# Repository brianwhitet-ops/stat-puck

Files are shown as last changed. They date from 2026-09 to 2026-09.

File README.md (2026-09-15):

# Stat Puck

Magnetic golf-cart score puck — e-ink + 5 buttons, offline on-course, BLE sync after the round.

## Repo

**https://github.com/brianwhitet-ops/stat-puck**

Full design pack zip: [v0.1.0 release](https://github.com/brianwhitet-ops/stat-puck/releases/tag/v0.1.0) (`stat-puck-full.zip`)

## Concepts

| On cart | In hand | Exploded | Mount |
| --- | --- | --- | --- |
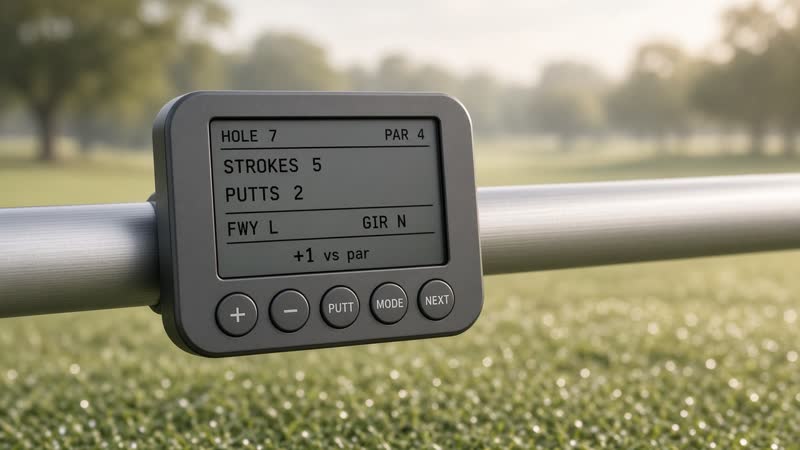
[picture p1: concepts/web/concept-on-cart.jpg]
on cart
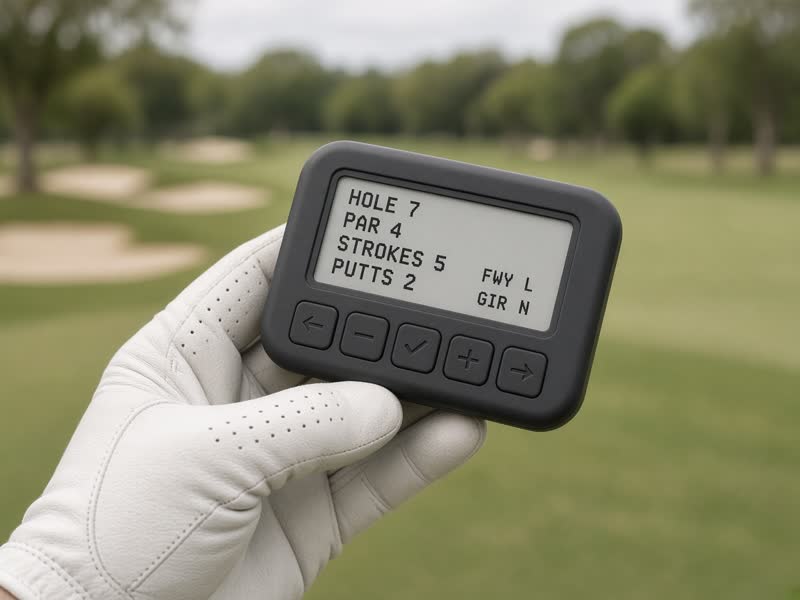
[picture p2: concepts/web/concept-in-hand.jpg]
in hand
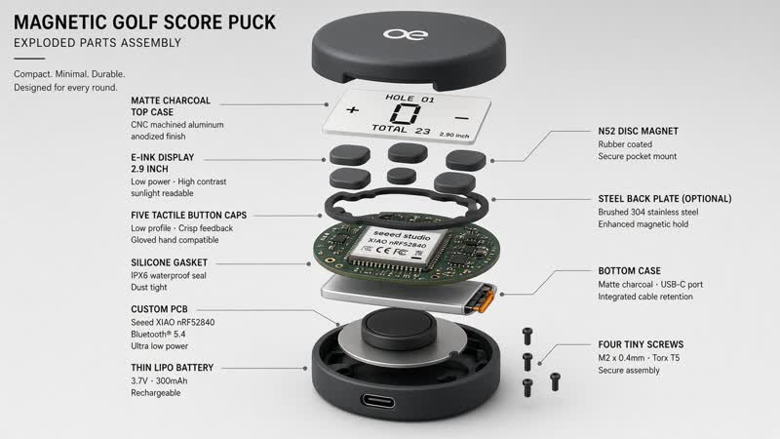
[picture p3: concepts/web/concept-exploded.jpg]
exploded
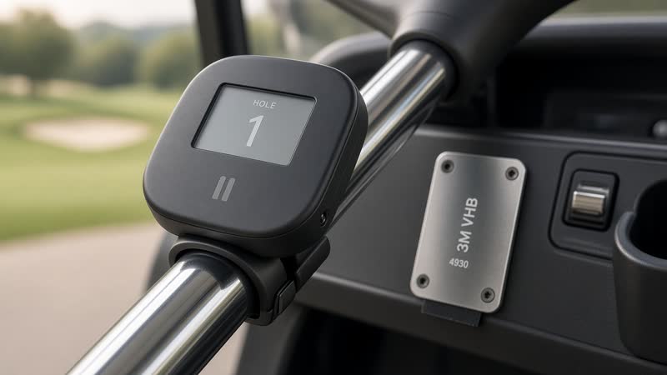
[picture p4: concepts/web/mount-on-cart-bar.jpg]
mount
|  |  |  |  |

## Assembly animation

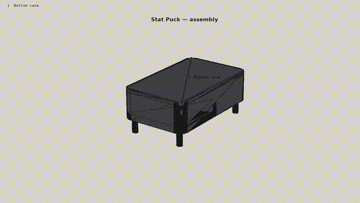
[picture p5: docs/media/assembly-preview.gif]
Assembly


Full MP4 is in the [v0.1.0 release zip](https://github.com/brianwhitet-ops/stat-puck/releases/download/v0.1.0/stat-puck-full.zip).

## Deliverables

| Path | What |
| --- | --- |
| `concepts/web/` | On-cart, in-hand, exploded, mount-on-bar concept images |
| `docs/SPEC.md` | One-page mechanical / electrical / firmware / cost spec |
| `docs/FIRMWARE_PLAN.md` | MVP tasks + 7-day bench plan |
| `docs/ORDER_MEMO.md` | What to order and why |
| `docs/RISKS.md` | Rental plastic, e-ink lag, bounce, NEXT, double-post, GHIN gate |
| `docs/SYNC_PAYLOAD.md` | Phone export schema (no invented GHIN API) |
| `bom/BOM.md` | Annotated BOM with vendor links + first-prototype cart |
| `cad/` | STEP + STL: enclosure, internals, steel plate, clamp |
| `docs/media/assembly-preview.gif` | Labeled assembly preview |
| `datasheets/` | Notes + linked vendor PDFs |
| `firmware/PINMAP.md` | Week-1 bring-up pin map |
| `firmware/` | Slab UI/state + host visual tests (`firmware/README.md`) |
| `design/instinct-firmware-goldens-pr1/` | Instinct-locked 296×128 goldens + SHA256SUMS |

## Device (P1)

- **MCU:** Seeed XIAO nRF52840 (USB-C, BLE) → production Raytac MDBT50Q-1MV2
- **Display:** Waveshare 2.9" e-Paper 296×128 (SPI)
- **Buttons:** 5× Omron B3W-1000 (IP67) — `+` `−` `PUTT` `MODE` `NEXT`
- **Magnet:** K&J DC6TP-N52 rubber-coated N52, **13.12 lb** Case-1 pull
- **Battery:** 500 mAh protected LiPo
- **Mount:** magnet pocket + steel plate/VHB for plastic carts + optional bar clamp

## UX (in-round)

```
HOLE 7  PAR 4
STROKES  5
PUTTS    2
FWY  L   GIR  N
+1
```

Defaults: strokes = par, putts = 2, GIR auto-suggest, FWY N/A on par 3. No rangefinder, no live GHIN, no on-device handicap.

## Regenerate CAD / animation

```bash
python3 cad/generate_enclosure.py
python3 animation/make_animation.py
```

## License

Prototype design files: MIT for CAD/firmware sketches. Vendor datasheets remain their respective copyrights.

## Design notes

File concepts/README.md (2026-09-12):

# Concepts

Web-optimized concept renders live in `web/`.

- On cart
- In hand
- Exploded
- Mount on cart bar

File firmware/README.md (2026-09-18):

# Slab firmware workstream

This branch builds on firmware PR #1. The companion app change builds on PR #3. Neither existing branch needs to be merged to review these changes, and no main branch merge or public website deployment is part of this work.

Read `../protocol/README.md` for the v2 contract and integration boundary. Read `../docs/SOFTWARE-HANDOFF-2026-09-18.md` for remaining vendor work.

## Implemented here

- Explicit zero-start capture flags; no par/two-putt/fairway prefills.
- Missing data stays null on the wire and stays out of statistics.
- Explicit 9/18 Quick Start and end-as-nine at the turn.
- Unique round ids from the XIAO silicon identity and a persisted sequence; golden fixtures are explicitly bench-only.
- Ten-round FIFO, queue-full backpressure, non-destructive chunk reads, identity/checksum-bound ACK retirement.
- Versioned two-slot save journal for active and completed rounds. UI/save failures stop progress instead of showing a false success.
- Protocol v2 C encoder with bounded output and a matching TypeScript implementation.

## Verification

```sh
make -C firmware/host test
make -C firmware/host visual
make -C firmware/host fixtures
python -m platformio run -e xiaoble -d firmware
```

Host tests run state, packed-device framebuffer, protocol/queue and byte-by-byte interrupted-write checks. `visual` compares six original fixtures without overwriting their goldens. Additional renders show zero-start and unentered-putt behavior. Tests are software evidence only.

## Still unimplemented or unverified

Real GATT advertising/transfer and ACK callbacks; phone/native BLE bridge; course-card download; signed DFU/rollback/provisioning; production board support; measured current and sleep optimization; real-panel refresh, button timing, RF range, environmental tests and physical power-cut testing. The existing blocking display driver pauses button polling during refresh and requires hardware timing work. No production battery-life claim is made.

Provision the filesystem separately on fresh boards. Normal startup only mounts it; it never invokes the SDK auto-format path. A mount failure shows a storage error and preserves the medium for service.

The selected development platform is the existing XIAO Adafruit/Arduino bench framework. This work does not select the production MCU, radio stack or bootloader. Large frame/store/journal workspaces are static to avoid overflowing the small Arduino loop-task stack. Integrators must serialize access and measure stack high-water and flash wear on hardware.

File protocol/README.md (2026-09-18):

# Slab round protocol v2

Implementation proposal for review, 2026-09-18. This supersedes the two incompatible round payload scaffolds in firmware PR #1 and app PR #3 on these new branches. It does not freeze production hardware or authorize changing the owner-approved battery, ingress, drop, mount or firmware-update requirements.

## Implementation boundary

The C encoder, queue/chunk reader, TypeScript decoder, receiver and durable import coordinator are implemented and software-tested. The XIAO radio remains a stub. There is no working GATT service, native iOS/Android BLE bridge, course-card receiver or DFU implementation in this change. Do not demonstrate an app simulation as a working wireless device.

The app and firmware PRs both carry the same `protocol/` directory. Before combining them, verify those files are identical. The app re-exports the shared TypeScript types; it does not maintain a third schema.

## Round payload

`schema_version` is now **2** because nullable capture fields, sequence and checksum semantics differ from both v1 scaffolds. Unsupported schemas and extra fields are preserved and rejected without ACK. No automatic v1 conversion is attempted: the old firmware cannot distinguish real input from its prefilled scores.

| Field | Rule |
| --- | --- |
| `schema_version` | Integer 2 |
| `round_id` | Opaque ASCII identifier, 1 to 64 characters from A-Z, a-z, 0-9, colon, underscore, hyphen |
| `device_id` | Same character set, 1 to 48 characters |
| `round_sequence` | Integer 1 through 4294967295, monotonically allocated and committed before play |
| `holes_played` | Numeric 9 or 18, explicitly chosen |
| `holes` | Exactly 9 or 18 entries in ascending contiguous order, including entries with unknown values |
| `hole` | Integer index 1 through `holes_played` |
| `par` | 3, 4, 5, or null when course metadata is unavailable |
| `strokes` | Entered integer 1 through 15, or null if unentered |
| `putts` | Entered integer 0 through 10, or null if unentered; entered putts require entered strokes and cannot exceed them |
| `drive_result` | `left`, `fairway`, `right`, or null; always null on par 3 |
| `totals.strokes`, `totals.putts` | Sum only when every hole has that field entered; otherwise null, never a misleading partial total |
| `checksum` | Lowercase `crc32:xxxxxxxx`, CRC-32/ISO-HDLC over the canonical UTF-8 body excluding this field |

GIR is derived only when par, strokes and putts are known. Unknown GIR is null, not false. Fairway percentages exclude unknown drive results and unknown course pars. The approved GIR approximation is retained; no extra shot-tracking facts are invented.

Canonical property order is defined by `canonicalBody()` and the C encoder. Hole properties are ordered `hole, par, strokes, putts, drive_result`. No whitespace is emitted. Unknown timestamps and course names are not fabricated; the app can attach course metadata and its own import timestamp outside the captured payload. CRC detects corruption; it is not authentication or a firmware signature.

`fixtures/` contains actual C output for untouched holes, a nine-hole round with explicitly entered zero putts, and a completed eighteen-hole fixture. App tests check those bytes against the TypeScript canonicalizer and checksum.

## Transfer and acknowledgment

1. Transfer is allowed only after round completion, in the sync screen. All accepted score changes and completed rounds must be persisted before a saved message or radio transfer is enabled.
2. Select the oldest queued round by device sequence, not a phone clock or similarity of course/date. One round transfers at a time.
3. The transport begins a transfer with the five `RoundAck` fields below plus `byte_length` (1 to 4096). It must bind the transfer to that exact immutable round.
4. Transfer chunks carry an explicit byte offset. Chunk size follows the negotiated transport capacity. The reference receiver accepts contiguous chunks and identical overlapping retransmissions. Gaps, changed replay bytes, overflow and incomplete payloads do not produce an ACK. Reconnect may safely restart at offset zero.
5. Parse, validate, checksum and compare transfer identity. Preserve unsupported raw payloads; keep the device copy. Never partially create a round.
6. Commit the validated round in a durable atomic app transaction. `round_id` is the idempotency key. An identical duplicate updates sync metadata only; it never replaces captured data, edits, provenance or the original import time. A different payload using the same id is a conflict and gets no ACK.
7. Only after that transaction completes may the app send ACK with `schema_version, round_id, device_id, round_sequence, checksum`.
8. The device checks all ACK fields against the oldest round in the session. Copy the store, apply `slab_store_ack`, persist the copy, then publish it and send a success result. If any step fails, retain the old store and report failure. A repeated ACK for an already removed round must not remove the next round. The low-level reference returns NOT_FOUND/CONFLICT in that case; the bridge should re-enumerate the queue.
9. `sendAck()` in the app must resolve on that persisted device result. An ATT write response alone is not proof the device committed retirement. If the result is lost, reconnect and re-enumerate; any retransmitted round is an idempotent duplicate.

The production BLE adapter must implement discovery/pairing, GATT UUIDs/characteristics, fragmentation of control messages, authorization of destructive ACKs, connection/session cleanup, retry timeouts and phone permission handling. Those transport decisions remain integration work; this document does not pretend to have selected or tested them. No firmware image bytes belong in this round service.

The app's IndexedDB adapter requires a transaction that reports `strict` durability and waits for its completion event. Engines that ignore the durability option receive no ACK. This follows the [IndexedDB durability contract](https://w3c.github.io/IndexedDB/#dom-idbtransaction-durability); software tests use an in-memory IndexedDB model and cannot prove phone disk behavior. Production integration still needs device testing, storage-retention policy and backup/recovery decisions.

## Device storage

The reference store supports one active round plus ten completed rounds, with backpressure before another round starts when the queue is full. Storage is a two-slot journal with version, size, sequence and CRC checks, flushed writes and readback. An interrupted inactive-slot write preserves the previous committed snapshot. Both slots corrupt or an old unsupported `/slab_round.bin` stops normal operation for service; it never silently resets the device.

The XIAO startup calls the base mount-only filesystem operation. Its usual `InternalFS.begin()` would auto-format on mount failure and is deliberately not used. A fresh unformatted device requires an explicit factory/service format; the application will not format it automatically.

Snapshots currently persist the versioned C structure layout. They are not a cross-compiler or future-firmware storage ABI. A production port must define and test migrations before changing layouts. A factory reset must preserve identity/sequence or provision a new identity namespace so old round ids cannot be reused.

These APIs use fixed workspaces and are serialized main-task APIs, not reentrant or ISR-safe. The device bridge must synchronize reads, saves, completion and ACK processing. The host file adapter is test infrastructure, not a certified database. A/B files share the underlying LittleFS medium; software fault tests do not establish real flash/brownout robustness, endurance, or the 30-day retention target.

## User interactions introduced for review

- Quick Start selects 9 or 18 holes with +/- and starts with NEXT. Unknown par/yardage remains unknown.
- Strokes begin at zero and require +/- entry. NEXT cannot promote an untouched zero into a score.
- Putts require explicit entry too. Minus at zero deliberately records a zero-putt hole; NEXT alone does not.
- Drive is initially unset. First + selects left; first - selects right; later inputs cycle L/fairway/R. Leaving it unset records null.
- At the turn, hold NEXT on untouched hole 10 to finish as nine. Holding NEXT after completion opens Quick Start for another round.
- NEXT is emitted on short release or once at the long-press threshold, never both. PUTT remains physically unchanged and ignored as in the approved sequential flow.

The original six visual fixture goldens remain unchanged. The new Quick Start, unentered fields and device storage-error screens need owner usability review and real-panel testing.

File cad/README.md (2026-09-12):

# CAD

Generate with `python3 cad/generate_enclosure.py` (build123d).

Exports: `device_assembly.step/.stl`, enclosure top/bottom, optional clamp, steel plate, cart mount demo.

Envelope 110×58×15.5 mm; magnet pocket Ø19.2×9.6; 5 buttons pitch 16 mm; USB-C on short edge.

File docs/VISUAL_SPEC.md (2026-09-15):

# Visual spec — Instinct REDO (296×128)

**Source of truth:** `design/instinct-firmware-goldens-pr1/`  
Hashes: `design/instinct-firmware-goldens-pr1/SHA256SUMS.txt`  
Note: `design/instinct-firmware-goldens-pr1/REDO-NOTE.md`

These native 296×128 RGBA frames replace the prior host 1-bit scorecard. No layout reinterpretation.

| File | State | Locked copy |
| --- | --- | --- |
| `01-default-hole.png` | `DEFAULT_HOLE` | Big score (par). `HOLE 07` · `PAR 4 · 412 YD`. `E · THROUGH 6`. No FWY/GIR. |
| `02-stroke-edit.png` | `STROKE_EDIT` | `STROKES` · − 4 + · `PRESS DIAL TO KEEP` |
| `03-putts-input.png` | `PUTTS_INPUT` | `PUTTS` · − 2 + · `PRESS DIAL TO KEEP` |
| `04-end-hole-confirm.png` | `END_HOLE_CONFIRM` | `DONE` · strokes/putts · drive LEFT / **FAIRWAY** / RIGHT · `PRESS DIAL` |
| `05-round-complete-sync.png` | `ROUND_COMPLETE_SYNC` | `ROUND COMPLETE` · 74 · +2 · `READY TO SYNC` · `OPEN SLAB ON PHONE` |
| `06-derived-stats.png` | `DERIVED_STATS` | `ROUND STATS` · GIR 11/18 61% · putting 31 / 1.72 per hole · `COMPUTED FROM SCORE+PUTTS` |
| `slab-screen-states-contact-sheet.png` | (sheet) | Instinct 2×3 |

Host `slab_ui_render` starts from the locked frame (zlib-baked in `firmware/src/slab_frames.c`) and composes live fields from `slab_round_t`. With the fixture/demo values these goldens encode, pixel-diff must be zero vs these PNGs. Other live values change those field pixels.

Behavior (unchanged): strokes → putts → done; no GIR prompt; drive L/fairway/R on par 4/5 only; BLE advertise only in `ROUND_COMPLETE_SYNC`.

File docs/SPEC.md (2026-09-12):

# Stat Puck — One-Page Spec

**Product:** Magnetic golf-cart score puck (Teenage Engineering–style slab)  
**Prototype codename:** `stat-puck`  
**Sync model:** Offline during round → BLE pull to phone after 18 (or 9) → phone posts later  

---

## Mechanical

| Item | Spec |
| --- | --- |
| Envelope | 110 × 58 × 15.5 mm, rounded slab, matte charcoal |
| Mass target | < 150 g (prototype estimate ~95–120 g) |
| Mount | N52 rubber-coated disc (K&J **DC6TP-N52**, Ø19.05 × 9.52 mm, **13.12 lb** Case-1 pull) in bottom pocket |
| Rental carts | Include 70 × 40 × 1.2 mm steel plate + 3M VHB tape (no ferrous metal on plastic bodies) |
| Optional | Secondary clamp for Ø22–28 mm Club Car / EZGO bar |
| Sealing | Silicone gasket in split line + IP67 Omron **B3W** switches; target **IP67-ish** (not lab-certified on rev A) |
| Aesthetic | Hidden M2 fasteners, no toy colors, no pelican ribs |

## Electrical

| Block | Choice | Notes from datasheets |
| --- | --- | --- |
| MCU + BLE | Seeed **XIAO nRF52840** (DigiKey 102010448) for P1; production → Raytac **MDBT50Q-1MV2** | USB-C, BLE 5.x, BQ25101 charger on XIAO; Raytac: 10.5×15.5×2.05 mm, VDD **1.7–5.5 V**, Nordic nRF52840 |
| Display | Waveshare **2.9" e-Paper** 296×128 | Panel outline **36.7×79.0×1.05 mm**; module **89.5×38 mm**; **4-wire SPI**; full refresh ~3 s, partial ~0.6 s; standby ≈0 |
| Buttons | 5× Omron **B3W-1000** | **IP67** (except terminals), bounce **≤5 ms**, OF **1.57 N** |
| Battery | Adafruit **1578** 3.7 V **500 mAh** LiPo w/ protection | 36×29×4.75 mm; charge via XIAO |
| Magnet | K&J **DC6TP-N52** | Rubber coat, water-resistant, non-scratch |

## Firmware states

```
BOOT → IDLE_PAIR → LOAD_CARD → IN_ROUND → TURN_SYNC? → END_ROUND_SYNC → SLEEP
```

Defaults: strokes=par, putts=2, GIR suggest `(strokes−putts)≤(par−2)`, FWY N/A on par 3. No on-device handicap. No live GHIN.

## Phone app (specify only)

Pick course + tees → push pars; pull card; one-screen edits; export payload; GHIN auth later (partner). Never invent a public GHIN API.

## BOM cost targets

| Qty | Target |
| --- | --- |
| 100 | **< $40** |
| 5 000 | **< $15** |

P1 shopping cart ~$70–90 (dev modules).

## Risks

Rental-cart plastic (need steel plate); e-ink lag (partial refresh); wet bounce (IP67+debounce); accidental NEXT (hold confirm); double-post (`round_id`); GHIN partner-gated.

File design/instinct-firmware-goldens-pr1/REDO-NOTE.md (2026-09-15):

# Instinct firmware visual REDO (2026-09-15 ~2:27pm ET)

Source: Instinct emails on lane.whitet@agentmail.to
- Main: Re: Brian connected us — Checkpoint verdict REDO visual layer
- Side: Slab firmware goldens 5-6 - use in PR #1

Order: Preserve behavior/state-machine; replace render layer. Check these native 296x128 PNGs into PR #1 as only visual source of truth; pixel-diff tests; no layout reinterpretation.

States:
1. 01-default-hole.png
2. 02-stroke-edit.png
3. 03-putts-input.png
4. 04-end-hole-confirm.png
5. 05-round-complete-sync.png
6. 06-derived-stats.png
+ slab-screen-states-contact-sheet.png

Next gate after emulator parity: on-device photos of all six under direct light + measured refresh.
States 5-6 UPDATED from Instinct goldens email (hashes differ from prior F-reference copies).

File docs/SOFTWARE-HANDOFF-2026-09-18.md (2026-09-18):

# Slab software handoff for scope review

Status: reviewable software implementation, not EVT validation. No communication has been sent to the manufacturer and no hardware has been purchased or ordered.

## Work supplied for review

| Area | Delivered | What the hardware partner retains |
| --- | --- | --- |
| Product behavior | Zero-start scoring, explicit capture, missing-data-aware statistics, 9/18 lifecycle, single-action NEXT handling | Real buttons, glove use, timing, display and usability integration |
| Round interface | One v2 schema, matching C/TypeScript encoders/validators and C-generated compatibility fixtures | BLE transport, pairing, GATT services, native phone integration and RF validation |
| Saved rounds | Ten-round queue, sequence identities, copy/commit ACK retirement and two-slot journal | Production NVM layout, migrations, flash wear, electrical power-loss tests and retention validation |
| App import | Bounded receiver, duplicate/conflict handling, IndexedDB transaction adapter and ACK-after-commit coordinator | Connecting these modules to the app UI/native BLE bridge and proving durability on representative phones |
| Verification | C state/protocol/fault tests, app transaction/compatibility tests and existing visual regression checks | End-to-end physical testing and defect correction |

The mobile app remains outside the manufacturer's quoted development scope. Its companion implementation supports integration and reduces overall project work; it does not by itself remove a line from their hardware fee.

## Scope that remains with the hardware partner

Production electrical architecture, component sourcing, schematic, PCB layout, antenna and magnet/cart interaction, charging and protection, production display selection, enclosure/clamp/seals, fabrication, assembly and integrated EVT validation. Signed BLE firmware update and recovery are still required and still unimplemented. No owner-approved battery, ingress, drop or RF target has been reduced.

There is no complete production CAD assembly, custom schematic or PCB supplied by this software change. Do not describe the original concept CAD as manufacturing-ready.

## Decisions made explicitly in this implementation

- Use schema v2 rather than relabeling incompatible v1 data.
- Represent unentered performance as null and use explicit capture flags on device.
- Require an explicit minus press to record zero putts. Untouched NEXT cannot fabricate a fact.
- Quick Start leaves par and yardage unknown until a course is supplied. No demo course is silently assigned.
- Use a ten-round capacity as the package's proposed implementation default, with no expiry or automatic eviction.
- Use mount-only startup rather than the SDK auto-format-on-failure routine. A fresh device requires factory/service filesystem provisioning.
- Preserve unsupported legacy files for service; no unsafe migration from prefilled scores.
- Keep the bench framework for now. Obtain vendor agreement before a production port or bootloader architecture is frozen.

## Acceptance before reducing outsourced scope

The partner should review the source, confirm which modules they will reuse, and price removed implementation separately from retained review, adaptation and integration. Source supplied is not automatically equivalent to supplier hours removed. Keep one named owner for integrated prototype behavior.

The statement of work should specify evidence for score capture, lossless queued sync, interrupted transfer, signed update/recovery and measured power, and distinguish EVT demonstrations from later DVT/certification work. Define included PCB/enclosure revision cycles and require editable source, schematics, PCB files, CAD and build instructions as deliverables.

## Validation record

- C host and packed-device logic tests: passed.
- Inactive-slot interruption tests: every one of 3,328 byte offsets passed on the host snapshot ABI.
- Invalid/corrupt slots and torn ACK retirement: passed in the injected storage model.
- App contract and import tests: 16 passed, including transaction completion before ACK, failed writes, unsupported durability, unknown schemas, duplicate import after reopen and concurrent duplicates.
- Six existing visual fixture images: pixel-identical, without golden replacement.
- App TypeScript/production build: passed.
- XIAO target build: passed, including linking and HEX/ZIP generation for `xiaoble_adafruit`. Linker-reported use is 35,236 of 237,568 bytes RAM and 146,284 of 811,008 bytes flash. This does not measure runtime stack/heap use or prove device operation.
- Build dependencies resolved to Nordic platform `10.1.0+sha.cac6fcf`, Seeed Adafruit framework `1.10101.0+sha.3ae21c3`, GCC ARM `7.2.1` and GxEPD2 `1.6.9`. Production dependency pinning remains a release-engineering task.
- Physical device, e-paper, flash durability, RF, DFU, power, ingress and drop evidence: none produced by this work.

Original package status was accurate for its pinned commits. This document describes the new work and does not alter that historical evidence record.

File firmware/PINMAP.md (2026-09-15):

# Firmware pin map (P1 breadboard → XIAO nRF52840)

Based on Seeed XIAO nRF52840 + Waveshare 2.9" e-Paper module datasheet pinout.

## E-ink (4-wire SPI)

| Module | XIAO | Notes |
| --- | --- | --- |
| VCC | 3V3 | 3.3 V |
| GND | GND | |
| DIN | D10 (MOSI) | SPI MOSI |
| SCLK | D8 (SCK) | SPI SCK |
| CS | D7 | low active |
| DC | D6 | high=data, low=cmd |
| RST | D3 | low active |
| BUSY | D1 | **high = busy** on Waveshare module |

Partial refresh for stroke/putt value edits; full refresh on state change / NEXT / confirm. BLE advertise only in `ROUND_COMPLETE_SYNC`.

Controller lock: **SSD1680** via **GxEPD2_290_T94_V2** (Waveshare 2.9" B/W V2/V3). See `firmware/README.md`.

## Buttons (Omron B3W-1000 → GND, INPUT_PULLUP)

Sequential lock: strokes → putts → done. No GIR pad.

| Button | GPIO | Behavior |
| --- | --- | --- |
| + | D2 | increment active field (enters `STROKE_EDIT` from default) |
| − | D4 | decrement (min strokes 1) |
| PUTT | D5 | wired, **ignored** (cannot skip to putts) |
| MODE | D0 | back one step; cycle drive L/FWY/R on confirm (par 4/5); toggle stats after 18 |
| NEXT | D9 | advance: default→stroke→putts→confirm→next hole / sync |

Software debounce **25 ms** (datasheet bounce ≤5 ms). Optional dial (unpopulated) shares the +/− path.

## Persistence

On-device LittleFS `/slab_round.bin` (18-hole card + UI). Host bench uses `firmware/testdata/nvram.bin`.

## Power

- JST LiPo on XIAO charge pad / battery pads per Seeed wiki
- USB-C for charge + UF2 flash
- Sleep between IRQs; power down panel between refreshes

## Out of scope

Cellular, rangefinder, shot tracking, AI caddie, touchscreen-first UI, on-device handicap, live GHIN.

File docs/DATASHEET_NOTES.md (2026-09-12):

# Datasheet notes (read for P1)

## Waveshare 2.9" EPD
- 296×128 B/W; panel 36.7×79×1.05 mm; module ~89.5×38 mm
- 4-wire SPI; BUSY high while busy; full ~3 s / partial ~0.6 s

## Omron B3W
- IP67 (excl. terminals); bounce ≤5 ms; OF 1.57 N / 2.26 N; 1–50 mA @ 3–24 VDC

## Raytac MDBT50Q-1MV2
- nRF52840; 10.5×15.5×2.05 mm; VDD 1.7–5.5 V; production MCU

## K&J DC6TP-N52
- Ø19.05×9.52 mm rubber-coated N52; Case-1 pull **13.12 lb**

## Adafruit 1578
- 3.7 V 500 mAh protected LiPo; UV cut ~3.0 V

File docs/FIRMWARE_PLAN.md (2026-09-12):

# Firmware MVP + Week-1 Bench Plan

## MVP tasks
1. XIAO bring-up + serial
2. 5× B3W debounce (20–30 ms); long-press PUTT −
3. Waveshare 2.9" SPI; partial on edits; full on NEXT
4. Hole struct + 18 NVM slots
5. Defaults + GIR suggest; FWY N/A on par 3
6. MODE cycle Fairway → GIR
7. NEXT lock + vs-par total
8. 9-hole mode flag
9. BLE GATT: CourseCard / RoundData / SyncControl
10. Sync protocol; mark synced; no mid-round GHIN
11. System OFF between IRQs
12. NEXT confirm on 9/18; ignore while BUSY

## Week-1
Day1 wire e-ink · Day2 buttons · Day3 round logic · Day4 BLE · Day5 print fit · Day6 mount · Day7 living-room 9 holes

Out of scope: rangefinder, shot track, AI caddie, touchscreen-first, cellular, on-device handicap, live GHIN.

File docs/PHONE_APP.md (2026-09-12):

# Phone app (specify only — do not ship App Store listing yet)

## Purpose
Bridge between Stat Puck and (later) GHIN. Device stays offline on-course.

## Screens (MVP)
1. **Course picker** — search course, choose tees, confirm hole count 9/18
2. **Push card** — write pars to device over BLE; show device battery
3. **Play** — status only (“recording on device”); no live score spam
4. **Pull & edit** — one-screen hole table; fix fat-finger mistakes
5. **Export / Post later** — package payload (`docs/SYNC_PAYLOAD.md`); GHIN auth placeholder

## Non-goals
- Inventing a public GHIN API
- Calculating official handicap on phone beyond what GHIN returns later
- Requiring cellular on the cart

## BLE services (draft)
- `CourseCard` — write JSON pars array
- `RoundData` — read/notify full round
- `SyncControl` — start/end sync, mark synced
- `DeviceInfo` — fw version, battery, round_id

## Score types
`Home` | `Away` | `Competition` — user picks before export.

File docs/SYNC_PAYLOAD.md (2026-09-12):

# Sync payload (phone ← device)

Device does **not** talk to GHIN. After the round (or at the turn), phone pulls this payload over BLE and may later post via a partner integration.

```json
{
  "schema": "stat-puck.round.v1",
  "round_id": "9f3c2e1a-7b84-4d2a-9c11-55aa01bf0e22",
  "device_id": "SPK-0001",
  "synced_at": "2026-09-12T18:44:00Z",
  "date": "2026-09-12",
  "course": {
    "name": "Example National",
    "tees": "Blue",
    "course_id": "local:example-national"
  },
  "holes_played": 18,
  "score_type": "Home",
  "holes": [
    {
      "hole": 1,
      "par": 4,
      "strokes": 5,
      "putts": 2,
      "fairway": "L",
      "gir": false
    }
  ]
}
```

### Field rules
- `fairway`: `H` | `L` | `R` | `NA` (forced `NA` on par 3)
- `gir`: boolean
- `score_type`: `Home` | `Away` | `Competition`
- `holes_played`: `9` or `18`
- No handicap fields on-device

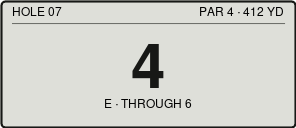
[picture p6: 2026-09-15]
design/instinct-firmware-goldens-pr1/01-default-hole.png

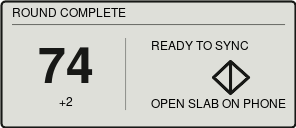
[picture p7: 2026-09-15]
design/instinct-firmware-goldens-pr1/05-round-complete-sync.png

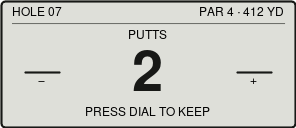
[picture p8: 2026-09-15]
design/instinct-firmware-goldens-pr1/03-putts-input.png

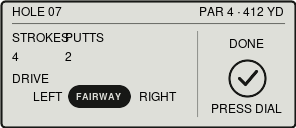
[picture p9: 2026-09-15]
design/instinct-firmware-goldens-pr1/04-end-hole-confirm.png

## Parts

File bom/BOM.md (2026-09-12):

# Annotated BOM — Stat Puck P1

See `bom/shopping_cart.csv` for the order-this-week cart (~$104 core / ~$129 w/ filament).

Primary P1 parts: Seeed XIAO nRF52840, Waveshare 2.9" e-Paper, Omron B3W-1000, Adafruit 1578 LiPo, K&J DC6TP-N52, steel plate + VHB.

Production: Raytac MDBT50Q-1MV2 + bare panel + custom PCB → **<$40 @100 / <$15 @5k**.

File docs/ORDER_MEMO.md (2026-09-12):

# What I ordered and why

1. **XIAO nRF52840 ×2** — USB-C + BLE + charger in stock; production → Raytac MDBT50Q
2. **Waveshare 2.9" e-Paper** — SPI, partial refresh, sunlight UI
3. **Omron B3W-1000 ×10** — IP67, ≤5 ms bounce
4. **Adafruit 1578 500 mAh ×2** — protected; ground ship
5. **K&J DC6TP-N52 ×2** — 13.12 lb Case-1; rubber coat
6. **Steel plate + 3M VHB** — rental plastic carts
7. **Printed enclosure + gasket + M2** — CAD in `cad/`

Non-orders: cellular, GPS, rangefinder, touchscreen, fake GHIN API, bare nRF52840 QFN for P1.

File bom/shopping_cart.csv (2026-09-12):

item | vendor | url | qty | unit_usd | ext_usd | notes
Seeed XIAO nRF52840 | DigiKey | https://www.digikey.com/en/products/detail/seeed-technology-co-ltd/102010448/16652893 | 2 | 9.96 | 19.92 | USB-C BLE MCU; ~4820 in stock
Waveshare 2.9in e-Paper Module | Waveshare/Pi Hut | https://thepihut.com/products/eink-display-module-spi-2-9-296x128 | 1 | 15.99 | 15.99 | 296x128 SPI; partial refresh
Omron B3W-1000 | DigiKey | https://www.digikey.com/en/products/detail/omron-electronics-inc-emc-div/B3W-1000/3700 | 10 | 0.40 | 4.00 | IP67 sealed tactile
Adafruit LiPo 500mAh 1578 | Adafruit | https://www.adafruit.com/product/1578 | 2 | 7.95 | 15.90 | Protected; ground ship only
K&J DC6TP-N52 magnet | K&J Magnetics | https://www.kjmagnetics.com/dc6tp-n52-neodymium-rubber-coated-disc-magnet | 2 | 7.73 | 15.46 | 13.12 lb Case-1 pull; rubber coat
Steel plate 70x40x1.2mm | McMaster/local | https://www.mcmaster.com/ | 2 | 3.00 | 6.00 | For plastic rental carts
3M VHB tape | McMaster | https://www.mcmaster.com/ | 1 | 4.00 | 4.00 | Bond plate to plastic
USB-C data cable | Adafruit/Amazon | https://www.adafruit.com/ | 1 | 5.00 | 5.00 | Flash + charge
Breadboard + jumpers | DigiKey | https://www.digikey.com/ | 1 | 8.00 | 8.00 | Week-1 wiring
M2 screws + inserts | McMaster | https://www.mcmaster.com/ | 1 | 6.00 | 6.00 | Hidden fasteners
Silicone gasket cord 1.5mm | McMaster | https://www.mcmaster.com/ | 1 | 4.00 | 4.00 | Split-line seal
PETG charcoal filament | local | n/a | 1 | 25.00 | 25.00 | Shared spool; print enclosure

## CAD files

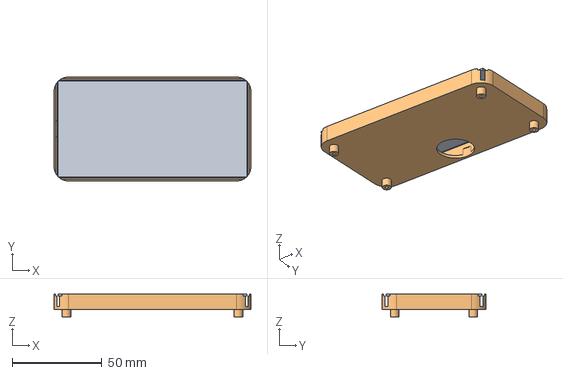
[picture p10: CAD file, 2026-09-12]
cad/enclosure_bottom.step
110.0 x 58.0 x 12.8 mm

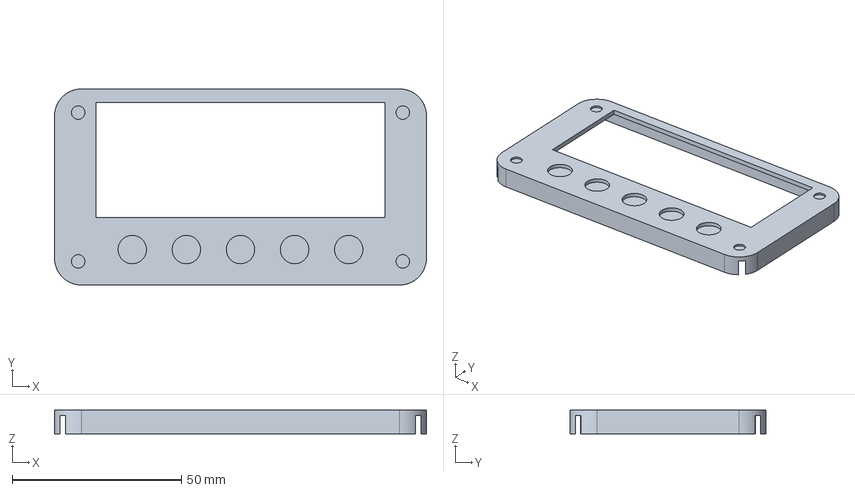
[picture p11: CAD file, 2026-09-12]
cad/enclosure_top.step
110.0 x 58.0 x 6.97 mm

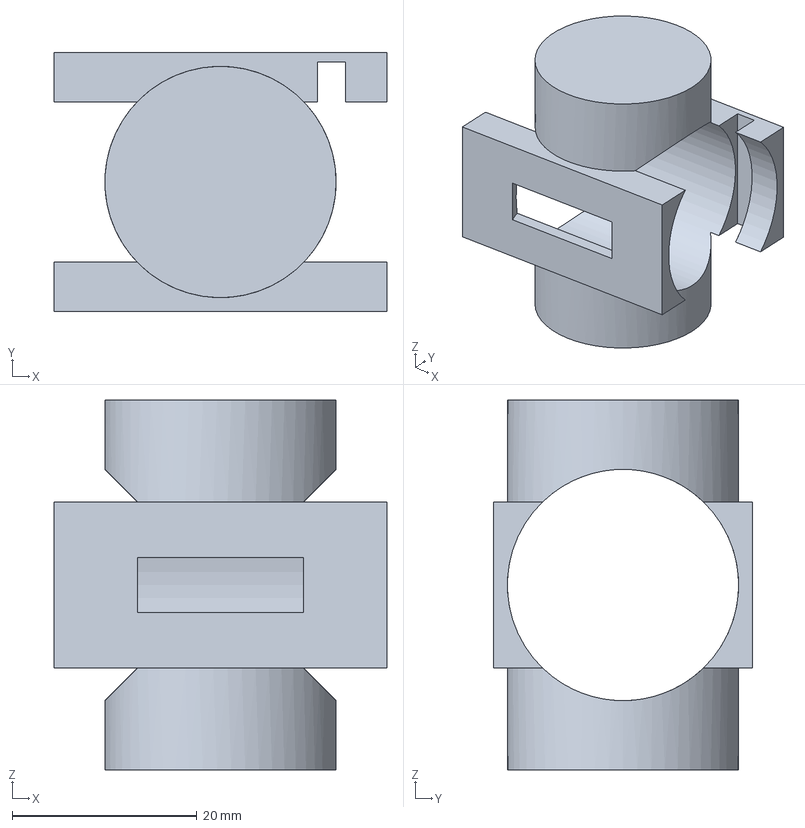
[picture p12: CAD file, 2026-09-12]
cad/optional_clamp.step
36.0 x 28.0 x 40.0 mm

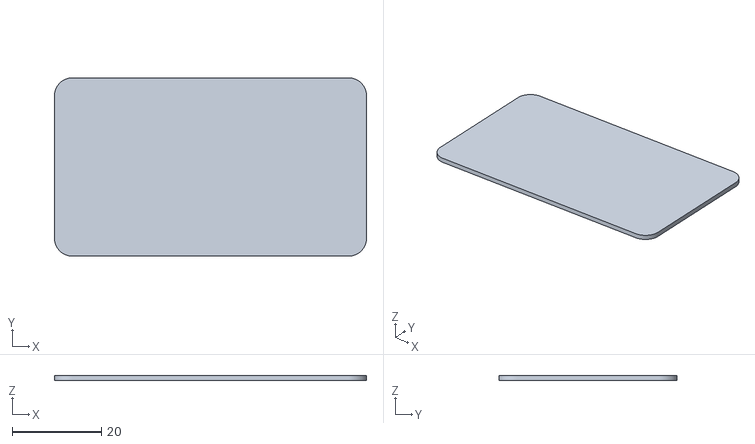
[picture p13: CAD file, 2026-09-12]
cad/steel_plate.stl
70.0 x 40.0 x 1.20

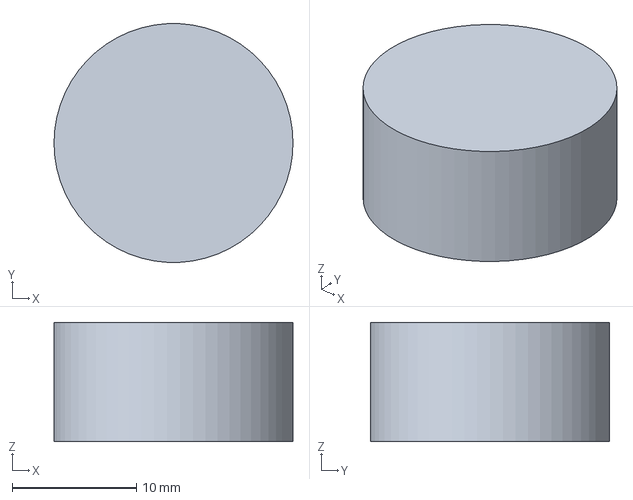
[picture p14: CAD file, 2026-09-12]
cad/magnet.step
19.2 x 19.2 x 9.60 mm

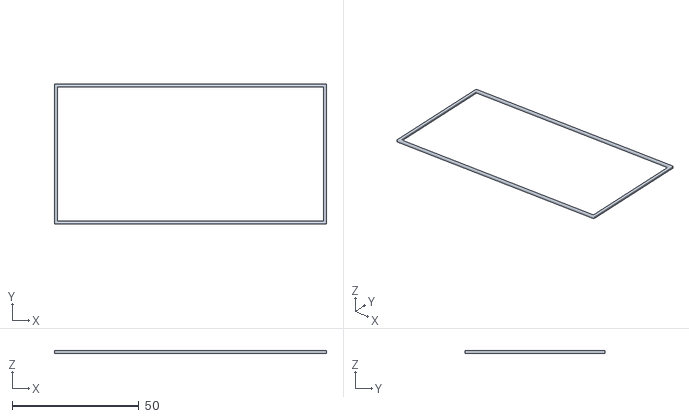
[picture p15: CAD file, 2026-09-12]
cad/gasket.stl
107.1 x 55.1 x 1.00

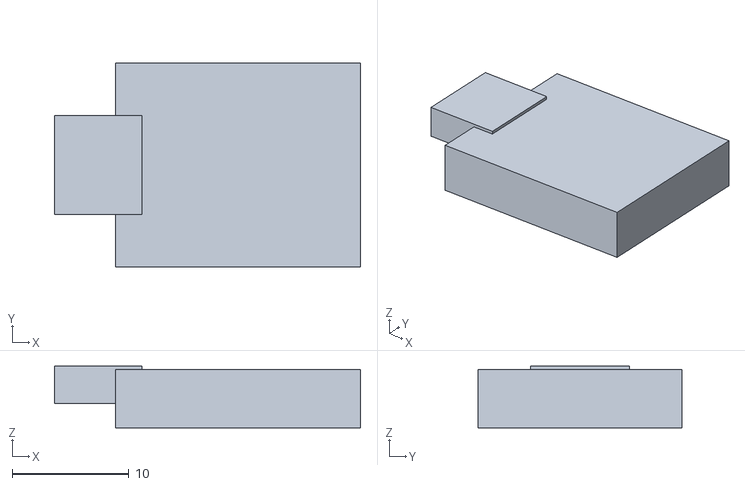
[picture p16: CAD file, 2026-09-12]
cad/xiao.stl
26.2 x 17.5 x 5.30

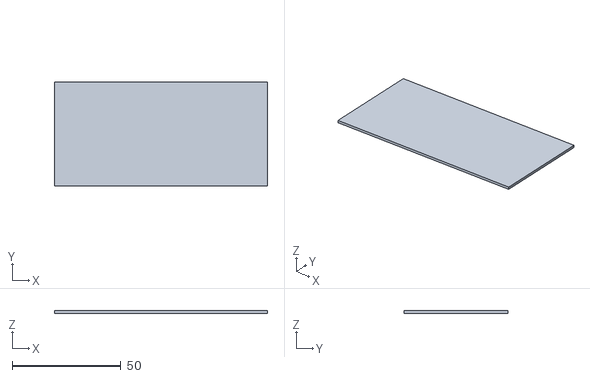
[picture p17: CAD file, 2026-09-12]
cad/pcb.stl
98.0 x 48.0 x 1.20

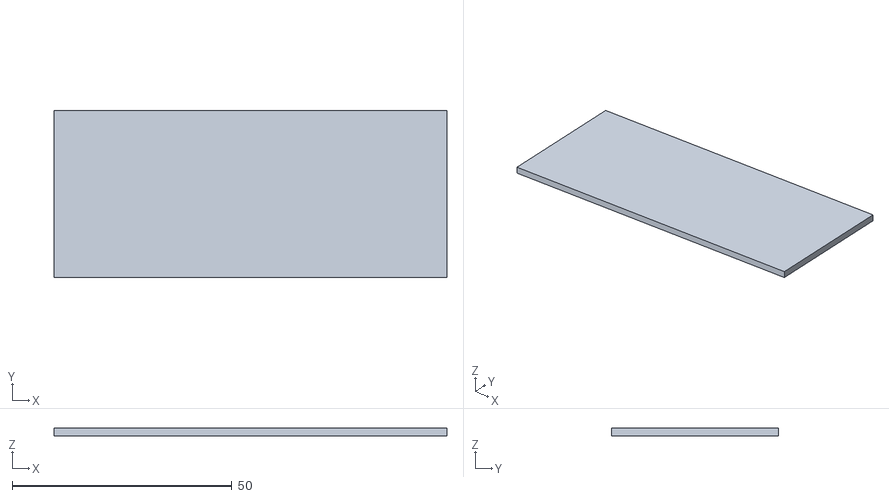
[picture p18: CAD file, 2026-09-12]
cad/eink.stl
89.5 x 38.0 x 1.80

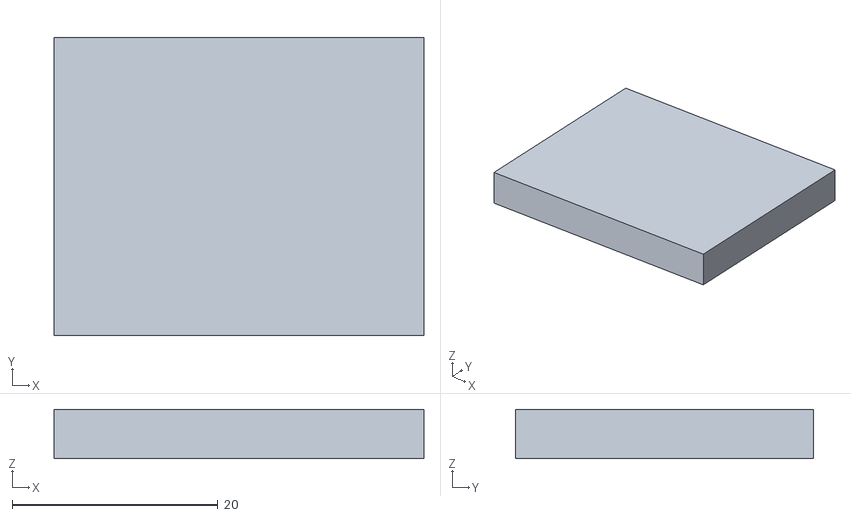
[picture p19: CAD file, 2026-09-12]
cad/battery.stl
36.0 x 29.0 x 4.80

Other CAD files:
cad/enclosure_bottom.stl
cad/enclosure_top.stl
cad/magnet.stl
cad/optional_clamp.stl

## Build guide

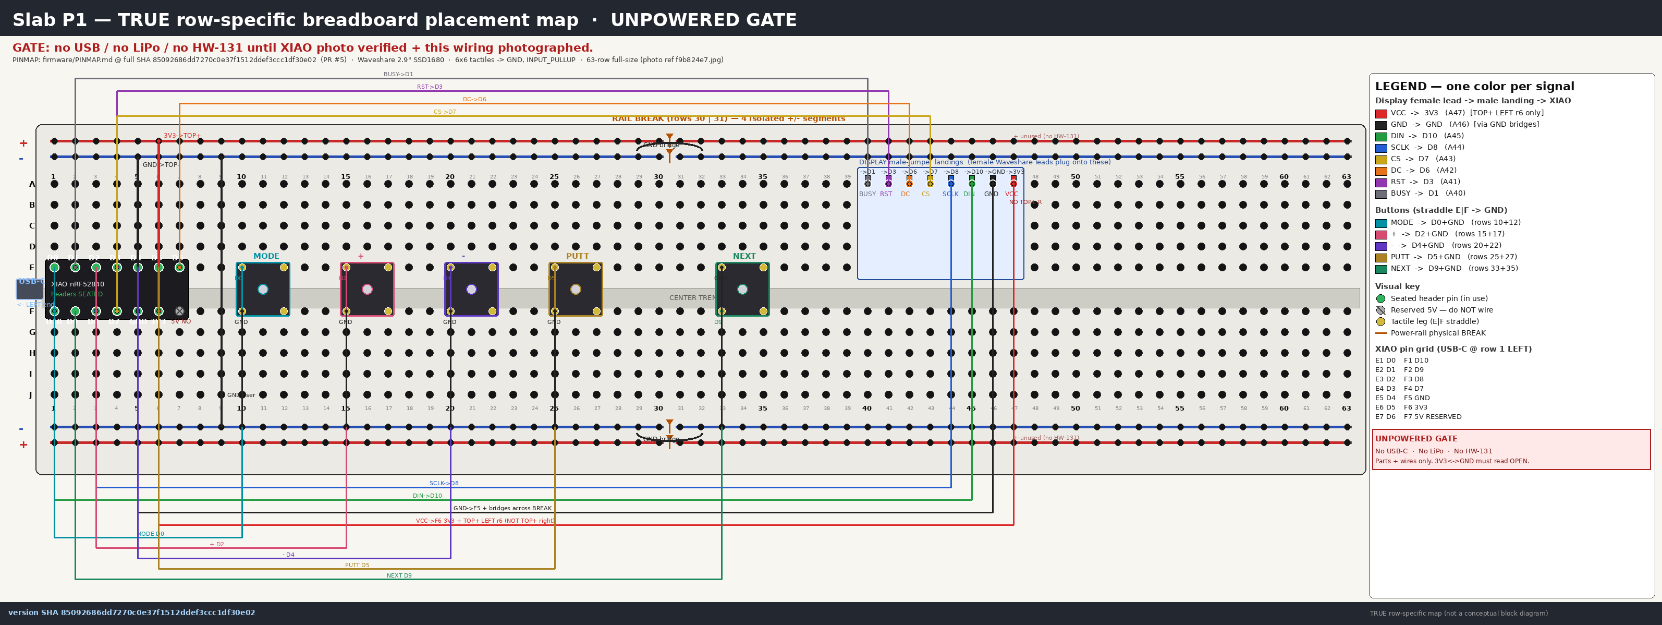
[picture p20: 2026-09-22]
docs/bench/slab-p1-row-specific-wiring-map.png

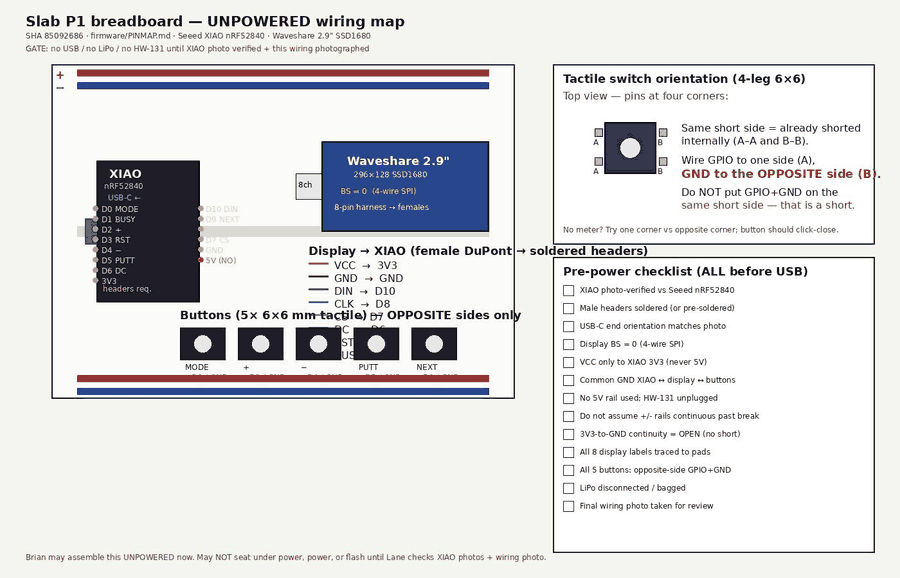
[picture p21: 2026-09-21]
docs/bench/slab-p1-breadboard-wiring-map.png

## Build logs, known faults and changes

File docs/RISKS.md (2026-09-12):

# Risks

| # | Risk | Mitigation |
| --- | --- | --- |
| 1 | Rental-cart plastic | Steel plate + VHB; optional clamp |
| 2 | E-ink lag | Partial refresh; don't block on BUSY |
| 3 | Wet bounce | B3W IP67 + ≥20 ms debounce |
| 4 | Accidental NEXT | Hold confirm on 9/18 |
| 5 | Double-post GHIN | round_id + posted flag |
| 6 | GHIN partner-gated | JSON/CSV export first |
| 7 | Magnet vs antenna | Pocket opposite chip antenna |
| 8 | USB-C sealing | Cap/flap on rev B |

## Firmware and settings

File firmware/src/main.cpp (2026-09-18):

#if !SLAB_HOST

#include <Arduino.h>
#include <SPI.h>
#include <GxEPD2_BW.h>
#include <Adafruit_LittleFS.h>
#include <InternalFileSystem.h>

extern "C" {
#include "slab_state.h"
#include "slab_ui.h"
#include "slab_input.h"
#include "slab_persist.h"
#include "slab_ble.h"
#include "slab_epd.h"
#include "slab_board.h"
#include "slab_font.h"
#include "slab_store.h"
}

using Adafruit_LittleFS_Namespace::File;
using Adafruit_LittleFS_Namespace::FILE_O_READ;
using Adafruit_LittleFS_Namespace::FILE_O_WRITE;

static GxEPD2_BW<GxEPD2_290_T94_V2, GxEPD2_290_T94_V2::HEIGHT> display(
    GxEPD2_290_T94_V2(SLAB_PIN_EPD_CS, SLAB_PIN_EPD_DC, SLAB_PIN_EPD_RST,
                      SLAB_PIN_EPD_BUSY));

static slab_store_t g_store;
static slab_store_t g_candidate;
static slab_fb_t g_fb;
static slab_round_t g_round;
static slab_input_t g_input;
static slab_epd_t g_epd;
static bool g_advertising;
static bool g_start_screen = true;
static bool g_storage_error;
static uint8_t g_selected_holes = 18;
static char g_device_id[SLAB_DEVICE_ID_SIZE];
static const char *kSlotPaths[] = {"/slab_store.0", "/slab_store.1"};

extern "C" int slab_persist_slot_write(unsigned slot, const void *data, unsigned len)
{
    if (slot > 1) return -1;
    // This is always the inactive journal slot. The committed slot is retained.
    if (InternalFS.exists(kSlotPaths[slot]) && !InternalFS.remove(kSlotPaths[slot])) return -1;
    File f(InternalFS);
    if (!f.open(kSlotPaths[slot], FILE_O_WRITE)) return -1;
    int n = f.write((const uint8_t *)data, len);
    f.flush();
    f.close();
    return n == (int)len ? 0 : -1;
}
extern "C" int slab_persist_slot_read(unsigned slot, void *data, unsigned len)
{
    if (slot > 1) return -1;
    if (!InternalFS.exists(kSlotPaths[slot])) {
        // Legacy data cannot tell entered scores from fabricated defaults.
        // Preserve it for explicit service migration; never erase or reset it.
        return InternalFS.exists("/slab_round.bin") ? SLAB_PERSIST_ERROR : SLAB_PERSIST_EMPTY;
    }
    File f(InternalFS);
    if (!f.open(kSlotPaths[slot], FILE_O_READ)) return -1;
    bool size_ok = f.size() == len;
    int n = f.read((uint8_t *)data, len);
    f.close();
    return size_ok && n == (int)len ? 0 : -1;
}

static void push_fb(const slab_fb_t *fb, slab_refresh_t mode)
{
    display.setRotation(1); /* 296 x 128 landscape */
    if (mode == SLAB_REFRESH_PARTIAL) {
        display.setPartialWindow(0, 0, SLAB_FB_W, SLAB_FB_H);
    } else {
        display.setFullWindow();
    }
    display.firstPage();
    do {
        for (int y = 0; y < SLAB_FB_H; y++) {
            for (int x = 0; x < SLAB_FB_W; x++) {
                display.drawPixel(x, y, slab_fb_get(fb, x, y) ? GxEPD_BLACK : GxEPD_WHITE);
            }
        }
    } while (display.nextPage());
    display.hibernate();
}

static void ble_gate_apply(void)
{
    bool want = !g_storage_error && !g_start_screen && !g_store.active_present &&
        g_store.count && slab_ble_should_advertise(&g_round);
    if (want == g_advertising) {
        return;
    }
    g_advertising = want;
    /*
     * Stub: Bluefruit advertising is started only here.
     * Mid-round states must never reach startAdvertising().
     */
    Serial.print("BLE advertise ");
    Serial.println(want ? "ON (ROUND_COMPLETE_SYNC)" : "OFF");
}

static const uint8_t kBtnPins[SLAB_BTN_COUNT] = {
    SLAB_PIN_BTN_PLUS, SLAB_PIN_BTN_MINUS, SLAB_PIN_BTN_PUTT, SLAB_PIN_BTN_MODE,
    SLAB_PIN_BTN_NEXT};

static void render_screen()
{
    slab_fb_t &fb = g_fb;
    if (g_storage_error || g_start_screen) {
        slab_fb_clear(&fb, 0);
        slab_text_m(&fb, 12, 12, g_storage_error ? "STORAGE ERROR" : "QUICK START", 1);
        if (g_storage_error) {
            slab_text_s(&fb, 12, 44, "NO DATA ERASED", 1);
            slab_text_s(&fb, 12, 65, "RESTART / SERVICE", 1);
        } else {
            char line[32];
            snprintf(line, sizeof(line), "%u HOLES", g_selected_holes);
            slab_text_m(&fb, 12, 42, line, 1);
            slab_text_s(&fb, 12, 68, "+/- 9 OR 18 / NEXT START", 1);
            snprintf(line, sizeof(line), "%u SAVED / MODE TO VIEW", g_store.count);
            slab_text_s(&fb, 12, 94, line, 1);
        }
    } else {
        slab_ui_render(&fb, &g_round);
        if (!g_store.active_present && g_round.ui == SLAB_UI_ROUND_COMPLETE_SYNC) {
            slab_fb_fill_rect(&fb, 6, 111, 284, 16, 0);
            slab_text_s(&fb, 8, 113, "SAVED / HOLD NEXT FOR NEW ROUND", 1);
        }
    }
    push_fb(&fb, SLAB_REFRESH_FULL);
    ble_gate_apply();
}

static bool commit_store(const slab_store_t &candidate)
{
    if (slab_persist_save_store(&candidate)) {
        g_storage_error = true;
        render_screen();
        return false;
    }
    g_store = candidate;
    return true;
}

void setup()
{
    Serial.begin(115200);
    snprintf(g_device_id, sizeof(g_device_id), "slab-%08lx%08lx",
             (unsigned long)NRF_FICR->DEVICEID[1], (unsigned long)NRF_FICR->DEVICEID[0]);
    for (int i = 0; i < SLAB_BTN_COUNT; i++) pinMode(kBtnPins[i], INPUT_PULLUP);
    // InternalFileSystem::begin auto-formats on mount failure. Use the base
    // mount-only operation so a damaged filesystem is never silently erased.
    // Fresh devices must be formatted by the factory/service provisioning step.
    bool fs_ok = InternalFS.Adafruit_LittleFS::begin();
    display.init(115200, true, 2, false);
    display.setRotation(1);
    slab_input_init(&g_input);
    slab_epd_init(&g_epd);
    int status = fs_ok ? slab_persist_load_store(&g_store) : SLAB_PERSIST_ERROR;
    if (status == SLAB_PERSIST_EMPTY) {
        slab_store_init(&g_store);
        g_storage_error = slab_persist_save_store(&g_store) != 0;
    } else g_storage_error = status != 0;
    if (!g_storage_error && g_store.active_present) {
        g_round = g_store.active;
        g_start_screen = false;
    } else if (!g_storage_error && g_store.count) {
        g_round = g_store.queued[g_store.count - 1];
        g_start_screen = false;
    }
    render_screen();
}

void loop()
{
    if (g_storage_error) { delay(10); return; }
    uint8_t raw[SLAB_BTN_COUNT];
    for (int i = 0; i < SLAB_BTN_COUNT; i++) raw[i] = digitalRead(kBtnPins[i]) == LOW ? 1 : 0;
    slab_evt_t ev = slab_input_poll(&g_input, raw, 10, 0, 0);
    if (ev == SLAB_EVT_NONE) { delay(10); return; }
    if (g_start_screen) {
        if (ev == SLAB_EVT_PLUS || ev == SLAB_EVT_MINUS) g_selected_holes = g_selected_holes == 9 ? 18 : 9;
        else if (ev == SLAB_EVT_NEXT) {
            g_candidate = g_store;
            slab_store_t &candidate = g_candidate;
            int result = slab_store_begin(&candidate, g_device_id, g_selected_holes, NULL);
            if (result == SLAB_STORE_FULL) {
                g_round = g_store.queued[0];
                g_start_screen = false;
            } else if (result || !commit_store(candidate)) {
                g_storage_error = true;
            } else {
                g_round = g_store.active;
                g_start_screen = false;
            }
        } else if (ev == SLAB_EVT_BACK && g_store.count) {
            g_round = g_store.queued[g_store.count - 1];
            g_start_screen = false;
        }
        render_screen();
    } else if (!g_store.active_present) {
        if (ev == SLAB_EVT_LONG_NEXT) g_start_screen = true;
        else (void)slab_apply_event(&g_round, ev);
        render_screen();
    } else {
        g_candidate = g_store;
        slab_store_t &candidate = g_candidate;
        slab_refresh_t hint = slab_apply_event(&candidate.active, ev);
        if (hint != SLAB_REFRESH_NONE) {
            slab_round_t next_view = candidate.active;
            if (slab_round_complete(&candidate.active) && slab_store_finish(&candidate)) {
                g_storage_error = true;
                render_screen();
                return;
            }
            // Commit before displaying a saved state or allowing sync.
            if (!commit_store(candidate)) return;
            g_round = next_view;
            slab_fb_t &fb = g_fb;
            slab_ui_render(&fb, &g_round);
            if (!g_store.active_present) render_screen();
            else {
                push_fb(&fb, slab_epd_choose(&g_epd, hint));
                ble_gate_apply();
            }
        }
    }
    delay(10);
}

#endif

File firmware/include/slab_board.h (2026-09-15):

#ifndef SLAB_BOARD_H
#define SLAB_BOARD_H

/* Seeed XIAO nRF52840 + Waveshare 2.9" B/W SPI. See firmware/PINMAP.md. */

#define SLAB_PIN_EPD_DIN 10 /* D10 MOSI */
#define SLAB_PIN_EPD_SCK 8  /* D8  SCK  */
#define SLAB_PIN_EPD_CS 7   /* D7  CS   */
#define SLAB_PIN_EPD_DC 6   /* D6  DC   */
#define SLAB_PIN_EPD_RST 3  /* D3  RST  */
#define SLAB_PIN_EPD_BUSY 1 /* D1  BUSY high=busy */

#define SLAB_PIN_BTN_PLUS 2  /* D2 */
#define SLAB_PIN_BTN_MINUS 4 /* D4 */
#define SLAB_PIN_BTN_PUTT 5  /* D5 — present, ignored by sequential lock */
#define SLAB_PIN_BTN_MODE 0  /* D0 */
#define SLAB_PIN_BTN_NEXT 9  /* D9 */

/* Optional quadrature dial (unpopulated on P1). Same +/- path as pads. */
#define SLAB_PIN_ENC_A (-1)
#define SLAB_PIN_ENC_B (-1)

#define SLAB_EPD_DRIVER "GxEPD2_290_T94_V2"
#define SLAB_EPD_CONTROLLER "SSD1680"
#define SLAB_EPD_PANEL "Waveshare 2.9 B/W V2/V3 (GDEM029T94 family)"

#endif

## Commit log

2026-09-12 Add BOM shopping cart, phone/sync docs, firmware pinmap
    [shopping_cart.csv]
2026-09-12 Add one-page SPEC, firmware plan, order memo, risks, datasheet notes, BOM
2026-09-12 Add CAD and animation generator scripts
2026-09-12 Fix cad/generate_enclosure.py with full CAD generator
2026-09-12 Add small CAD STL placeholders (battery, eink, pcb, xiao, gasket)
    [battery.stl, eink.stl, gasket.stl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]
2026-09-12 Add cad/magnet.step
    [magnet.step]
2026-09-12 chore: stage upload part _upload/magnet.stl.b64.0
2026-09-12 Add concepts/web/mount-on-cart-bar.jpg
2026-09-12 Add cad/magnet.stl
    [magnet.stl]
2026-09-12 Add cad/steel_plate.stl
    [steel_plate.stl]
2026-09-12 Add docs/media/assembly-preview.gif
2026-09-12 Add cad/optional_clamp.stl
    [optional_clamp.stl]
2026-09-12 Add cad/optional_clamp.step
    [optional_clamp.step]
2026-09-12 Add cad/enclosure_top.stl
    [enclosure_top.stl]
2026-09-12 Add cad/enclosure_bottom.stl
    [enclosure_bottom.stl]
2026-09-12 Add cad/enclosure_top.step
    [enclosure_top.step]
2026-09-12 Add cad/enclosure_bottom.step
    [enclosure_bottom.step]
2026-09-15 Add Slab firmware visual-parity checkpoint (296x128)
    Host-testable UI/state machine matching the locked e-ink scorecard:
    strokes → putts → done, GIR derived only, BLE advertise gated to
    ROUND_COMPLETE_SYNC. SSD1680 / GxEPD2_290_T94_V2 refresh policy,
    25 ms pad debounce, hole persistence, and six golden 296x128 frames.
2026-09-15 Match Instinct REDO goldens exactly on the host renderer
    Keep the strokes→putts→done state machine. Replace the 1-bit
    scorecard blit with the locked 296×128 RGBA frames, SHA256SUMS
    verification, and zero-diff pixel tests against the Instinct pack.
2026-09-15 Fix host -Werror and add device 1-bit Instinct frames
    Drop the unsigned putts vs SLAB_PUTTS_MIN compare so visual builds
    clean. Ship packed 296x128 1-bit panel frames on the non-host path
    (no RGBA/zlib on XIAO). Add par 4/5 drive-cycle tests.
2026-09-15 Compose 1-bit frames from live round state
    Device render no longer blits a fixed PNG per UI enum. Chrome still
    comes from the Instinct template; strokes, putts, hole, drive, and
    totals are stamped from slab_round_t. Fixture/demo values leave those
    pixels alone so host visual stays 0-diff against the goldens. Device
    tests assert packed buffers change when those fields change.
2026-09-15 Make pio run -e xiaoble succeed on the XIAO tree
    Official nordicnrf52@11 has no xiaoble board. Point the existing env at
    the maxgerhardt fork + xiaoble_adafruit (Adafruit LittleFS), fix the
    src filter so firmware/src is actually compiled, and compile setup/loop
    when SLAB_HOST is 0 rather than only when it is undefined.
    [main.cpp]
2026-09-21 docs: add Slab P1 breadboard wiring diagram (PNG) for Instinct verify
2026-09-21 docs: add Slab P1 breadboard wiring diagram (JPG) for Instinct verify
2026-09-22 docs: Slab P1 TRUE row-specific breadboard wiring map (PNG)
2026-09-22 docs: Slab P1 TRUE row-specific breadboard wiring map (JPG)
